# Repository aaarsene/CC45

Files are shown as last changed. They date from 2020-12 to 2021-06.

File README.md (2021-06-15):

# CC45

THIS IS A WORK IN PROGRESS

⚠️ **Switch spacing is 19mm** ⚠️

[Interactive BOM](http://htmlpreview.github.io/?https://github.com/aaarsene/CC45/blob/master/bom/ibom.html)

## Supported layouts

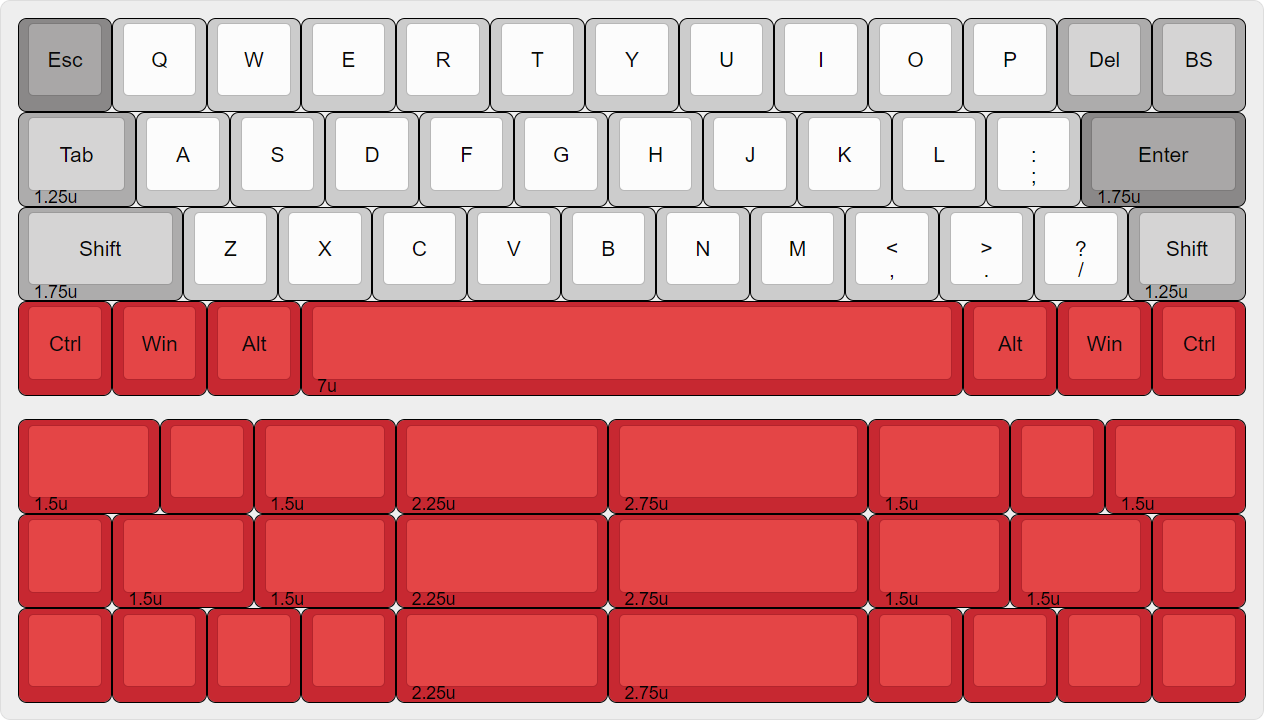
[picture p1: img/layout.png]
supported layouts


## PCB Render

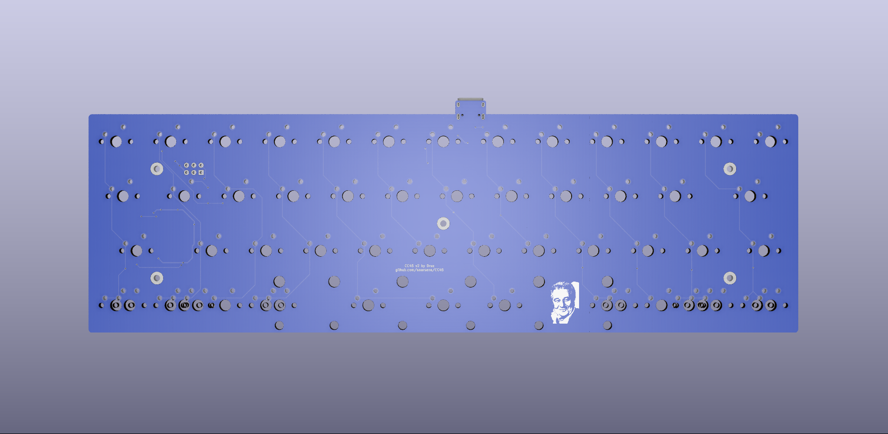
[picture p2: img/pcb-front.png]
pcb front


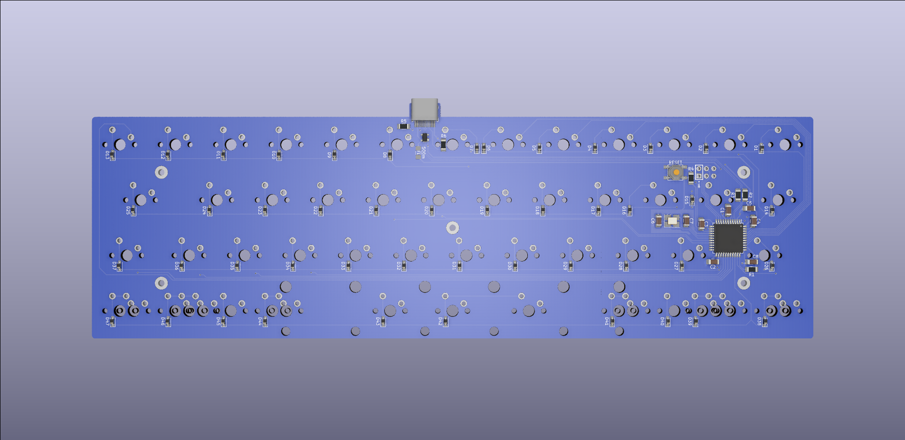
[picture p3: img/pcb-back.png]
pcb back


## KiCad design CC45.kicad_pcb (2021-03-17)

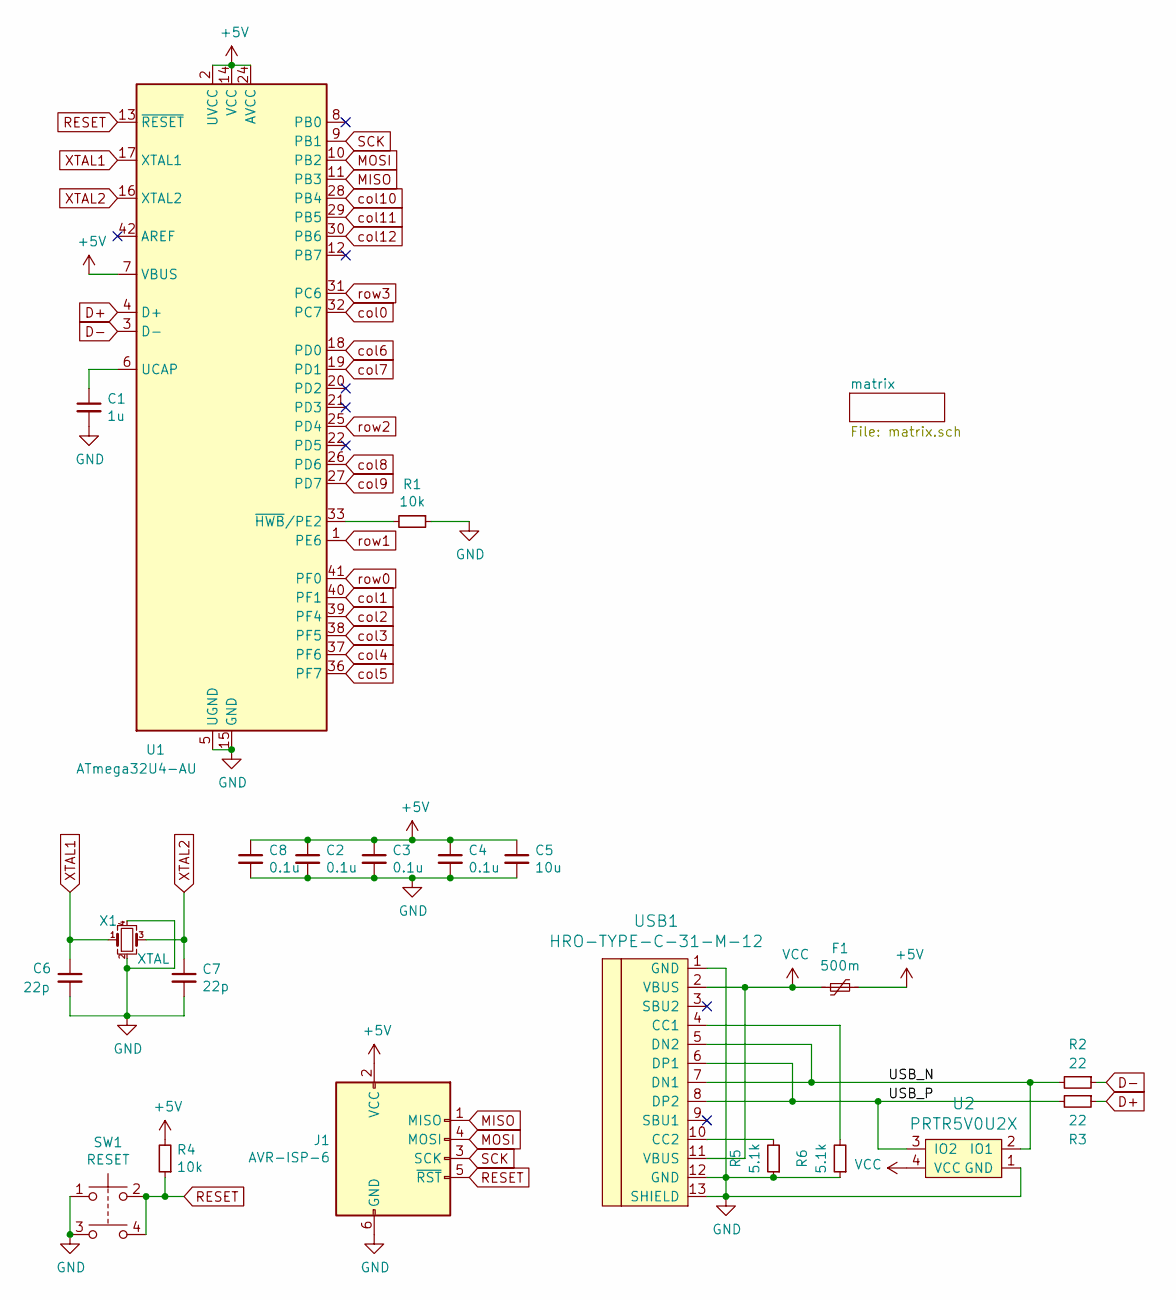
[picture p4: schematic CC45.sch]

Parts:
C1: 1u; C_1206_3216Metric_Pad1.42x1.75mm_HandSolder; LCSC C1848
C2, C3, C4, C8: 0.1u; C_1206_3216Metric_Pad1.42x1.75mm_HandSolder; LCSC C24497
C5: 10u; C_1206_3216Metric_Pad1.42x1.75mm_HandSolder; LCSC C13585
C6, C7: 22p; C_1206_3216Metric_Pad1.42x1.75mm_HandSolder; LCSC C313096
F1: 500m; Fuse_1206_3216Metric_Pad1.42x1.75mm_HandSolder; LCSC C151162
J1: AVR-ISP-6; Reset_Pretty-Mask
R1, R4: 10k; R_1206_3216Metric_Pad1.42x1.75mm_HandSolder; LCSC C17902
R2, R3: 22; R_1206_3216Metric_Pad1.42x1.75mm_HandSolder; LCSC C17958
R5, R6: 5.1k; R_1206_3216Metric_Pad1.42x1.75mm_HandSolder; LCSC C26033
SW1: RESET; SKQG-1155865; LCSC C318884
U1: ATmega32U4-AU; TQFP-44_10x10mm_P0.8mm; LCSC C44854
U2: PRTR5V0U2X; SOT143B; LCSC C78442
USB1: HRO-TYPE-C-31-M-12; HRO-TYPE-C-31-M-12-HandSoldering
X1: XTAL; Crystal_SMD_3225-4Pin_3.2x2.5mm_HandSoldering; LCSC C13738

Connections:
+5V: C2.1, C3.1, C4.1, C5.1, C8.1, F1.1, J1.2 (VCC), R4.2, U1.2 (UVCC), U1.7 (VBUS), U1.14 (VCC), U1.24 (AVCC), U1.34 (VCC), U1.44 (AVCC)
/USB_N: R2.2, U2.2 (IO1), USB1.5 (DN2), USB1.7 (DN1)
/USB_P: R3.2, U2.3 (IO2), USB1.6 (DP1), USB1.8 (DP2)
D+: R3.1, U1.4 (D+)
D-: R2.1, U1.3 (D-)
GND: C1.2, C2.2, C3.2, C4.2, C5.2, C6.2, C7.2, C8.2, J1.6 (GND), R1.1, R5.1, R6.1, SW1.1, SW1.3, U1.5 (UGND), U1.15 (GND), U1.23 (GND), U1.35 (GND), U1.43 (GND), U2.1 (GND), USB1.1 (GND), USB1.12 (GND), USB1.13 (SHIELD), X1.2, X1.4
MISO: J1.1 (MISO), U1.11 (PB3)
MOSI: J1.4 (MOSI), U1.10 (PB2)
unnamed: C1.1, U1.6 (UCAP)
unnamed: R1.2, U1.33 (~HWB~/PE2)
unnamed: R5.2, USB1.10 (CC2)
unnamed: R6.2, USB1.4 (CC1)
RESET: J1.5 (~RST), R4.1, SW1.2, SW1.4, U1.13 (~RESET)
SCK: J1.3 (SCK), U1.9 (PB1)
VCC: F1.2, U2.4 (VCC), USB1.2 (VBUS), USB1.11 (VBUS)
XTAL1: C6.1, U1.17 (XTAL1), X1.1
XTAL2: C7.1, U1.16 (XTAL2), X1.3
col0: U1.32 (PC7); also elsewhere on the board
col1: U1.40 (PF1); also elsewhere on the board
col2: U1.39 (PF4); also elsewhere on the board
col3: U1.38 (PF5); also elsewhere on the board
col4: U1.37 (PF6); also elsewhere on the board
col5: U1.36 (PF7); also elsewhere on the board
col6: U1.18 (PD0); also elsewhere on the board
col7: U1.19 (PD1); also elsewhere on the board
col8: U1.26 (PD6); also elsewhere on the board
col9: U1.27 (PD7); also elsewhere on the board
col10: U1.28 (PB4); also elsewhere on the board
col11: U1.29 (PB5); also elsewhere on the board
col12: U1.30 (PB6); also elsewhere on the board
row0: U1.41 (PF0); also elsewhere on the board
row1: U1.1 (PE6); also elsewhere on the board
row2: U1.25 (PD4); also elsewhere on the board
row3: U1.31 (PC6); also elsewhere on the board

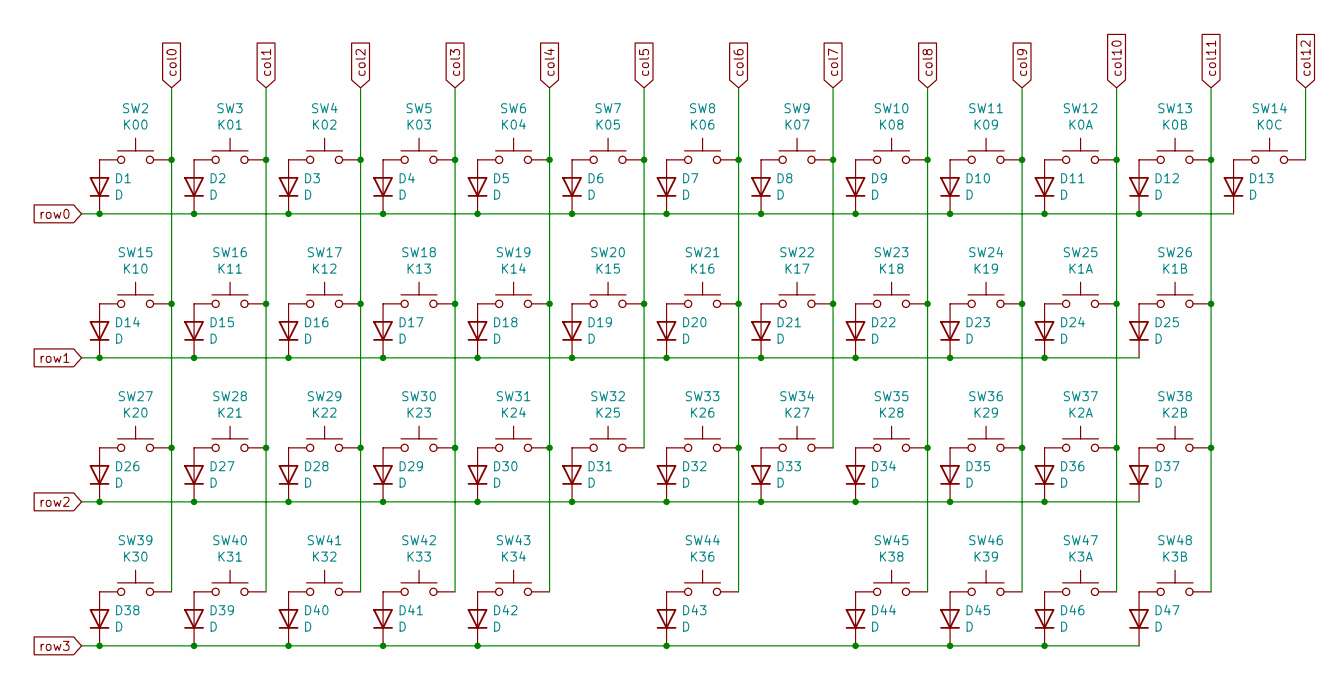
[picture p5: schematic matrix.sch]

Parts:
D1, D2, D3, D4, D5, D6, D7, D8, D9, D10, D11, D12, D13, D14, D15, D16, D17, D18, D19, D20, D21, D22, D23, D24, D25, D26, D27, D28, D29, D30, D31, D32, D33, D34, D35, D36, D37, D38, D39, D40, D41, D42, D43, D44, D45, D46, D47: D; D_SOD-323_HandSoldering; LCSC C84063
SW2: K00; MX_19mm-1U-NoLED
SW3: K01; MX_19mm-1U-NoLED
SW4: K02; MX_19mm-1U-NoLED
SW5: K03; MX_19mm-1U-NoLED
SW6: K04; MX_19mm-1U-NoLED
SW7: K05; MX_19mm-1U-NoLED
SW8: K06; MX_19mm-1U-NoLED
SW9: K07; MX_19mm-1U-NoLED
SW10: K08; MX_19mm-1U-NoLED
SW11: K09; MX_19mm-1U-NoLED
SW12: K0A; MX_19mm-1U-NoLED
SW13: K0B; MX_19mm-1U-NoLED
SW14: K0C; MX_19mm-1U-NoLED
SW15: K10; MX_19mm-1.25U-NoLED
SW16: K11; MX_19mm-1U-NoLED
SW17: K12; MX_19mm-1U-NoLED
SW18: K13; MX_19mm-1U-NoLED
SW19: K14; MX_19mm-1U-NoLED
SW20: K15; MX_19mm-1U-NoLED
SW21: K16; MX_19mm-1U-NoLED
SW22: K17; MX_19mm-1U-NoLED
SW23: K18; MX_19mm-1U-NoLED
SW24: K19; MX_19mm-1U-NoLED
SW25: K1A; MX_19mm-1U-NoLED
SW26: K1B; MX_19mm-1.75U-NoLED
SW27: K20; MX_19mm-1.75U-NoLED
SW28: K21; MX_19mm-1U-NoLED
SW29: K22; MX_19mm-1U-NoLED
SW30: K23; MX_19mm-1U-NoLED
SW31: K24; MX_19mm-1U-NoLED
SW32: K25; MX_19mm-1U-NoLED
SW33: K26; MX_19mm-1U-NoLED
SW34: K27; MX_19mm-1U-NoLED
SW35: K28; MX_19mm-1U-NoLED
SW36: K29; MX_19mm-1U-NoLED
SW37: K2A; MX_19mm-1U-NoLED
SW38: K2B; MX_19mm-1.25U-NoLED
SW39: K30; MX_19mm-1.25U-NoLED
SW40: K31; MX_19mm-1U-NoLED
SW41: K32; MX_19mm-1.25U-NoLED
SW42: K33; MX_19mm-1.25U-NoLED
SW43: K34; MX_19mm-1.75U-NoLED
SW44: K36; MX_19mm-1.75U-NoLED
SW45: K38; MX_19mm-1.25U-NoLED
SW46: K39; MX_19mm-1.25U-NoLED
SW47: K3A; MX_19mm-1U-NoLED
SW48: K3B; MX_19mm-1.25U-NoLED

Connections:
unnamed: D1.2 (A), SW2.1
unnamed: D2.2 (A), SW3.1
unnamed: D3.2 (A), SW4.1
unnamed: D4.2 (A), SW5.1
unnamed: D5.2 (A), SW6.1
unnamed: D6.2 (A), SW7.1
unnamed: D7.2 (A), SW8.1
unnamed: D8.2 (A), SW9.1
unnamed: D9.2 (A), SW10.1
unnamed: D10.2 (A), SW11.1
unnamed: D11.2 (A), SW12.1
unnamed: D12.2 (A), SW13.1
unnamed: D13.2 (A), SW14.1
unnamed: D14.2 (A), SW15.1
unnamed: D15.2 (A), SW16.1
unnamed: D16.2 (A), SW17.1
unnamed: D17.2 (A), SW18.1
unnamed: D18.2 (A), SW19.1
unnamed: D19.2 (A), SW20.1
unnamed: D20.2 (A), SW21.1
unnamed: D21.2 (A), SW22.1
unnamed: D22.2 (A), SW23.1
unnamed: D23.2 (A), SW24.1
unnamed: D24.2 (A), SW25.1
unnamed: D25.2 (A), SW26.1
unnamed: D26.2 (A), SW27.1
unnamed: D27.2 (A), SW28.1
unnamed: D28.2 (A), SW29.1
unnamed: D29.2 (A), SW30.1
unnamed: D30.2 (A), SW31.1
unnamed: D31.2 (A), SW32.1
unnamed: D32.2 (A), SW33.1
unnamed: D33.2 (A), SW34.1
unnamed: D34.2 (A), SW35.1
unnamed: D35.2 (A), SW36.1
unnamed: D36.2 (A), SW37.1
unnamed: D37.2 (A), SW38.1
unnamed 46: D38.2 (A), SW39.1; also elsewhere on the board
unnamed 47: D39.2 (A), SW40.1; also elsewhere on the board
unnamed: D40.2 (A), SW41.1
unnamed 49: D41.2 (A), SW42.1; also elsewhere on the board
unnamed 50: D42.2 (A), SW43.1; also elsewhere on the board
unnamed: D43.2 (A), SW44.1
unnamed 52: D44.2 (A), SW45.1; also elsewhere on the board
unnamed: D45.2 (A), SW46.1
unnamed 54: D46.2 (A), SW47.1; also elsewhere on the board
unnamed 55: D47.2 (A), SW48.1; also elsewhere on the board
col0: SW2.2, SW15.2, SW27.2, SW39.2; also elsewhere on the board
col1: SW3.2, SW16.2, SW28.2, SW40.2; also elsewhere on the board
col2: SW4.2, SW17.2, SW29.2, SW41.2; also elsewhere on the board
col3: SW5.2, SW18.2, SW30.2, SW42.2; also elsewhere on the board
col4: SW6.2, SW19.2, SW31.2, SW43.2; also elsewhere on the board
col5: SW7.2, SW20.2, SW32.2; also elsewhere on the board
col6: SW8.2, SW21.2, SW33.2, SW44.2; also elsewhere on the board
col7: SW9.2, SW22.2, SW34.2; also elsewhere on the board
col8: SW10.2, SW23.2, SW35.2, SW45.2; also elsewhere on the board
col9: SW11.2, SW24.2, SW36.2, SW46.2; also elsewhere on the board
col10: SW12.2, SW25.2, SW37.2, SW47.2; also elsewhere on the board
col11: SW13.2, SW26.2, SW38.2, SW48.2; also elsewhere on the board
col12: SW14.2; also elsewhere on the board
row0: D1.1 (K), D2.1 (K), D3.1 (K), D4.1 (K), D5.1 (K), D6.1 (K), D7.1 (K), D8.1 (K), D9.1 (K), D10.1 (K), D11.1 (K), D12.1 (K), D13.1 (K); also elsewhere on the board
row1: D14.1 (K), D15.1 (K), D16.1 (K), D17.1 (K), D18.1 (K), D19.1 (K), D20.1 (K), D21.1 (K), D22.1 (K), D23.1 (K), D24.1 (K), D25.1 (K); also elsewhere on the board
row2: D26.1 (K), D27.1 (K), D28.1 (K), D29.1 (K), D30.1 (K), D31.1 (K), D32.1 (K), D33.1 (K), D34.1 (K), D35.1 (K), D36.1 (K), D37.1 (K); also elsewhere on the board
row3: D38.1 (K), D39.1 (K), D40.1 (K), D41.1 (K), D42.1 (K), D43.1 (K), D44.1 (K), D45.1 (K), D46.1 (K), D47.1 (K); also elsewhere on the board

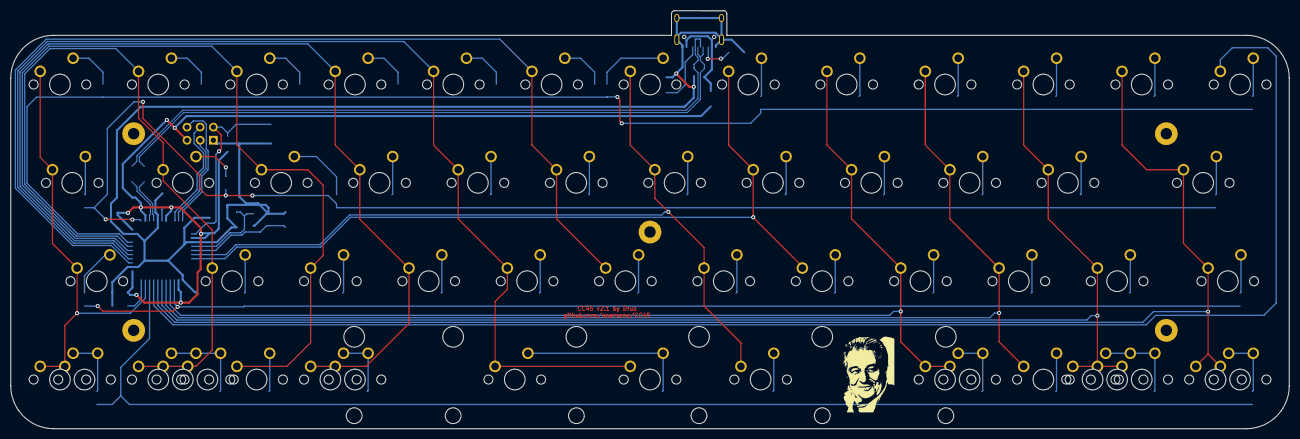
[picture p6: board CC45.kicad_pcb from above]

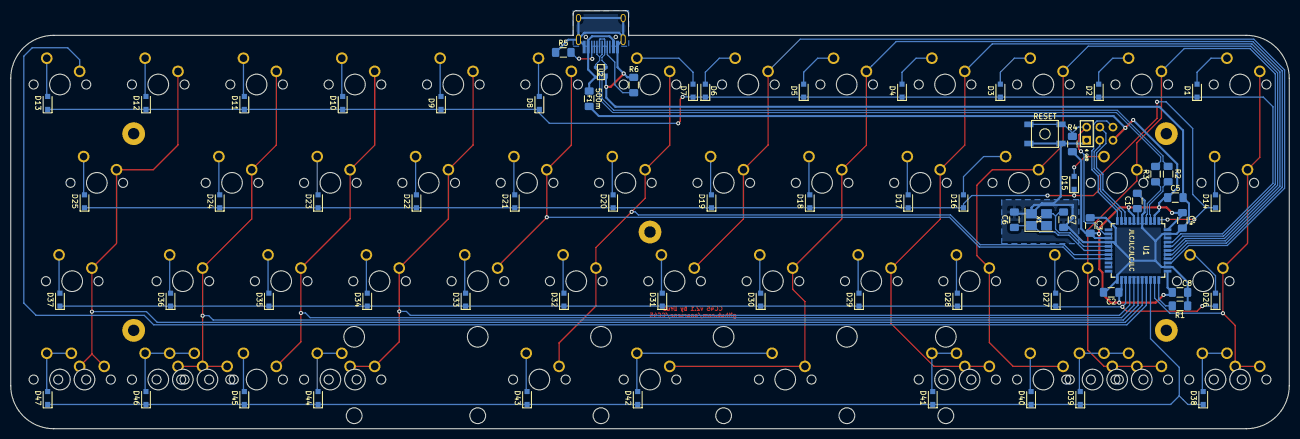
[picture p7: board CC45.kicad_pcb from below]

Board: 2 copper layers, 247.0 x 80.8 mm, 124 parts (68 on the bottom side), 81 nets.

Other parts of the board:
SW39#2: K30; MX_19mm-1U-NoLED
SW40#2, SW40#3: K31; MX_19mm-1U-NoLED
SW42#2: K33; MX_19mm-1U-NoLED
SW43#2: K34; MX_19mm-2.25U-ReversedStabilizers-NoLED
SW45#2: K38; MX_19mm-1U-NoLED
SW47#2, SW47#3: K3A; MX_19mm-1U-NoLED
SW48#2: K3B; MX_19mm-1U-NoLED

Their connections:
unnamed 46: SW39#2.1; also elsewhere on the board
unnamed 47: SW40#2.1, SW40#3.1; also elsewhere on the board
unnamed 49: SW42#2.1; also elsewhere on the board
unnamed 50: SW43#2.1; also elsewhere on the board
unnamed 52: SW45#2.1; also elsewhere on the board
unnamed 54: SW47#2.1, SW47#3.1; also elsewhere on the board
unnamed 55: SW48#2.1; also elsewhere on the board
col0: SW39#2.2; also elsewhere on the board
col1: SW40#2.2, SW40#3.2; also elsewhere on the board
col3: SW42#2.2; also elsewhere on the board
col4: SW43#2.2; also elsewhere on the board
col8: SW45#2.2; also elsewhere on the board
col10: SW47#2.2, SW47#3.2; also elsewhere on the board
col11: SW48#2.2; also elsewhere on the board

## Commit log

2020-06-15 Add libraries to kicad project
2020-06-15 created mcu schematic
    [CC45.sch]
2020-06-15 add switch matrix and assign footprints
    [CC45.kicad_pcb, CC45.sch, matrix.sch]
2020-06-16 changed switches footprint submodule
2020-06-16 Placed footprints on pcb and routed everything except the matrix
    [CC45.kicad_pcb, CC45.sch, matrix.sch]
2020-06-16 rework components postion around the mcu and usb
    [CC45.kicad_pcb]
2020-06-17 Connect matrix to mcu on the schema and moved some components around
    [CC45.kicad_pcb, CC45.sch]
2020-06-17 Routed the matrix
    [CC45.kicad_pcb, CC45.sch]
2020-06-17 moved values on silkscreen to make them more visible
    [CC45.kicad_pcb]
2020-06-18 modified the pcb file to be compatible with the latest stable release of kicad
    [CC45.kicad_pcb]
2020-06-18 Add a decoupling capacitor
    [CC45.kicad_pcb, CC45.sch, matrix.sch]
2020-06-18 Add fill zones
    [CC45.kicad_pcb, CC45.sch]
2020-06-19 Visual improvements, mostly on the silkscreen
    [CC45.kicad_pcb]
2020-06-21 moving C4 closer to the mcu and adding JLC parts numbers
    [CC45.kicad_pcb, CC45.sch, matrix.sch]
2020-06-21 moved the middle mounting point to the center of the pcb
    [CC45.kicad_pcb]
2020-06-21 Added gerber files
    [CC45-B_Cu.gbr, CC45-B_Mask.gbr, CC45-B_Paste.gbr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]
2020-07-02 added the 1u keys for the 1.5u bottom row option
    [CC45.kicad_pcb]
2020-07-03 fix reset button wiring
    [CC45.kicad_pcb]
2020-07-05 Updated version number on pcb
    [CC45.kicad_pcb]
2020-07-05 removed gerber from source control
    [CC45-B_Cu.gbr, CC45-B_Mask.gbr, CC45-B_Paste.gbr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]
2020-11-07 v2 update
    [CC45.kicad_pcb, CC45.sch]
2020-12-27 Added interactive bom
2020-12-29 Update link to interactive bom
2021-01-06 Increased corner radius
    [CC45.kicad_pcb]
2021-03-17 Updated version written on pcb
    [CC45.kicad_pcb]
2021-06-15 Add warning about switch spacing
